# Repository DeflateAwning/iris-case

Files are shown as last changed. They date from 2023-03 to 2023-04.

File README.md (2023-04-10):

Iris Keyboard Case
==================

This repo contains the [Iris keyboard case](https://keeb.io/products/iris-keyboard-split-ergonomic-keyboard) design files. The case is a sandwich-style case with cutouts to accommodate the USB jack and the inter-half jack.

DeflateAwning Variation
-----------------------

The DeflateAwning variation removes the bottom FR/acrylic layer, decreasing the thickness of the whole board by 1.6mm, and simplifying the part count.

This version is for the Iris Rev 6, and has been tested on the Iris Rev. 6.1 PCB only. It may be compatible with other ones, but it might not be.

### Other changes:
* Uses M2x8mm thread-forming screws instead of bolts.
* Adds 3d-printable rubber feet.
* Adds "fuzzy skin" section to edges to make it easier to grip the edges of the keyboard and pull it into place.
* Smaller reset hole.

### Coming soon:
* Tenting stand.
* Better rotary encoder knobs.

**The rest of this README is copied from the upstream fork, and may not be accurate anymore.**

Please star my fork if you like this design, and especially if you end up printing/testing it. Feel free to open an Issue to request a feature.

Case pieces
-----------

The Iris sandwich case consists these pieces:

- Switch plate (Required)
- Bottom plate (Required)
- Middle layer (Optional)
- Top rim or Top shell (Optional)

### Case/Plate Versions

Before the release of the Iris Rev. 5 PCBs, the case parts for Rev. 3 & 4 used the same parts. However, with the release of Rev. 5-7 PCBs, the screw holes needed to be relocated to accommodate the wider USB-C port used for interconnect. Therefore, new case parts needed to be made to support the newer PCBs.

The newer case parts are called [Phoenix Edition (PE)](phoenix-edition-PE/), while the older Iris parts are now called [Legacy Edition (LE)](legacy-edition-LE).

Phoenix Edition parts and Legacy Edition parts are not compatible with each other due to the different placement of screw holes.

PE parts are compatible with Rev. 3 through 7 PCBs.

LE parts are compatible with Rev. 3 & 4 PCBs.

See additional info about Legacy Edition files in its [README](legacy-edition-LE/README.md).

Iris PE (Phoenix Edition) Parts
-------------------------------
### 3D-print STL files

For the 3D-print STL files, there are two sets of files, ones for the top shell, and ones for the middle layer. For each of these sets, there are different files based on how thick your plates are. If you have the FR4 plates or Stainless steel plates, then use the files for 1.5mm plate. If you are using 3mm acrylic plates, then use the files for the 3mm plate.

For the middle layer files for 1.5mm plates, there are two sets of files: one with a lip and one without a lip. The "lip" refers to the portion of the middle layer that extends past the standoffs and covers the sides of the 1.5mm plate, to hide the edges from view. The "No Lip" version may be more desirable for you to use if you are not using a top shell.

If you are using the top shells, you will need to use longer M2 screws, as the top shell has been designed to be threaded into directly from underneath. For 1.5mm plates, you will need [18mm screws](https://keeb.io/products/m2-screws-and-standoffs), and for 3mm plates, you will need 22mm screws.

If you choose to print the ErgoDox-style tenting legs, you will need six M3 screws (at least 16mm) and six M3 nuts. The legs and washers are best printed at 0.16mm quality or better.

Additional notes
----------------

Some of the files only have a left half, just mirror the file to produce a right half if needed.

Design info
-----------

A lot of these files have been derived from the following file: [iris-plate-design.ai](references/iris-plate-design.ai). By toggling various layers in that file, you can see various info on switch cutouts, screw holes, inner/outer edges, etc.

Screws and Standoffs
--------------------

This case was designed to use M2 screws and standoffs. The holes in the middle layers are for the standoffs, while the holes in the top and bottom layers are only wide enough for the screws. M2 screws and standoffs that fit the case can be purchased at Keebio: [M2 Screws & Standoffs](https://keeb.io/products/m2-screws-and-standoffs)

Fabrication of Acrylic Parts
----------------------------

### Places to go

- [Sculpteo](https://www.sculpteo.com)
- [Ponoko](https://www.ponoko.com)

### Middle Layer Thickness
If you're having the middle layers made, from the top of the switch plate to the top of the bottom plate, the minimum distance between the two required is 12mm if the plastic on the header pins is removed. The requirement is slightly more (about 13.5mm) if you leave the plastic on. Therefore, the following middle layer thickness are needed based on the thickness of the switch layer:

- 1.5mm Stainless steel switch plate: 10.5mm
    - Usually accomplished with:
        - 2x4.5mm + 1x1.5mm layers
        - or 3x3mm + 1x1.5mm layers
        - or 4x3mm layers
- 3mm acrylic switch plate: 9mm
    - Usually accomplished with:
        - 2x4.5mm layers
        - or 3x3mm layers

STL Files for 3D printing
-------------------------
A couple of STL files have also been included for the middle layers and are both single pieces. They are designed for the left half, so to get the right half, you will need to flip them within your slicer software.

One version allows the Ergodox EZ legs to be used with it. In addition to the legs, you'll need M3 nuts to allow the legs screws to screw into.

Community-Made Files
--------------------
Files not designed by Keebio are placed into the [community-made](community-made/) folder and also includes links to other designs not hosted in this repository.

License
-------
These case files are released under the MIT License.

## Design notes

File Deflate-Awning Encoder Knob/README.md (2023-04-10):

# Deflate-Awning Encoder Knob

An encoder knob for the standard encoder on the Iris keyboard.

## Print Settings
* Enable Fuzzy Skin
* Make Fuzzy Skin deeper by 0.5mm

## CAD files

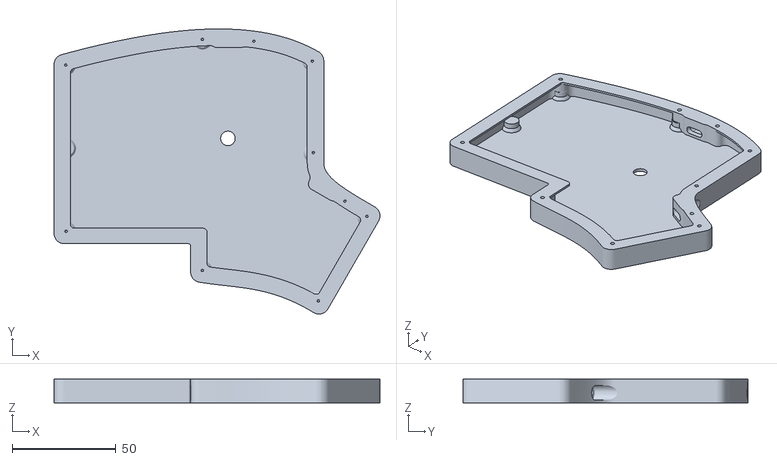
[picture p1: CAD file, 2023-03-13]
phoenix-edition-PE/DeflateAwning Version/Iris PE Redesign v1 - Main Case.stl
157.4 x 137.7 x 11.5

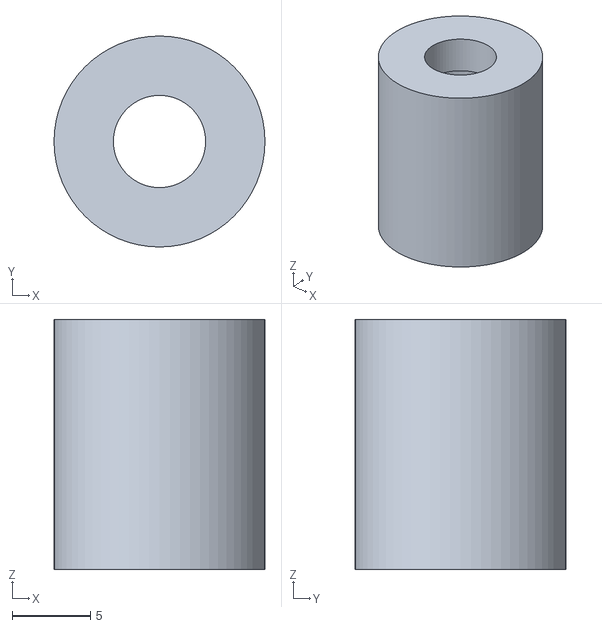
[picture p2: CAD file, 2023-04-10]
Deflate-Awning Encoder Knob/KeyboardEncoderKnob.stl
13.5 x 13.5 x 16.0

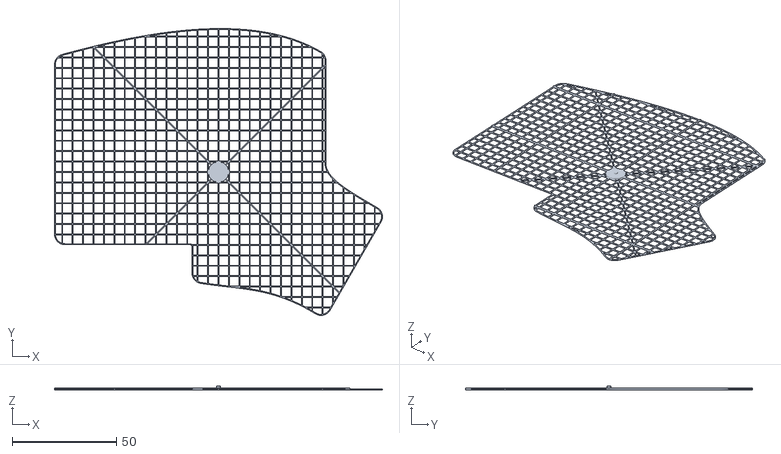
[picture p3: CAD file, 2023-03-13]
phoenix-edition-PE/DeflateAwning Version/Iris PE Redesign v1 - 5mm Test Grid.stl
157.4 x 137.7 x 1.80

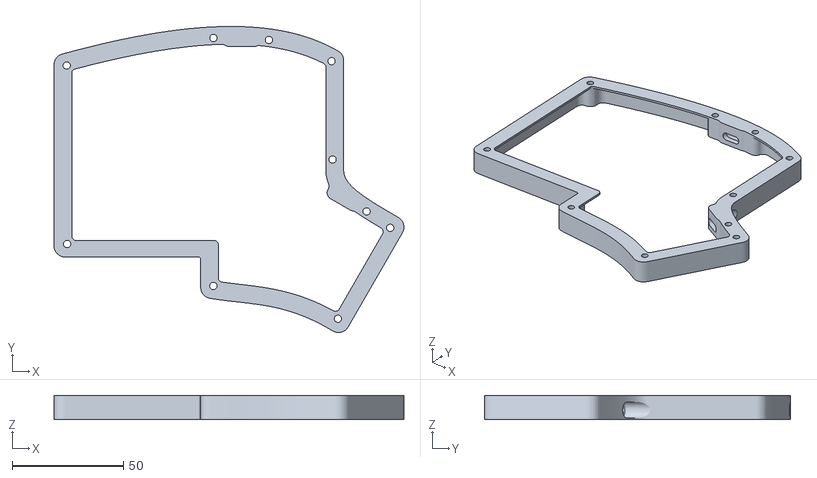
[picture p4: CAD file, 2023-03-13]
phoenix-edition-PE/Iris PE Middle Layer - Normal No Lip for 1.5mm Plate - Centered.stl
157.4 x 137.7 x 11.0

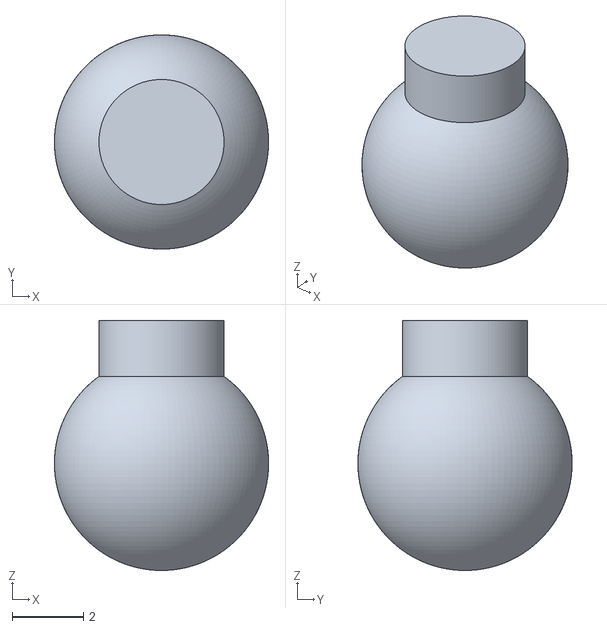
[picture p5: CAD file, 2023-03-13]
phoenix-edition-PE/DeflateAwning Version/Iris PE Redesign v1 - Balls.stl
6.00 x 6.00 x 7.00

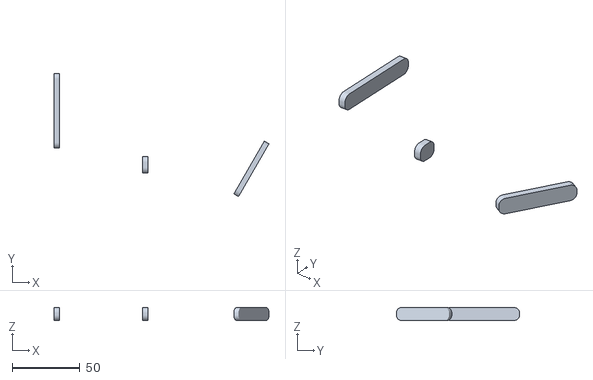
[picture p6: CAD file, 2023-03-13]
phoenix-edition-PE/DeflateAwning Version/Iris PE Redesign v1 - fuzzy_region_modifier.stl
158.7 x 91.0 x 9.50

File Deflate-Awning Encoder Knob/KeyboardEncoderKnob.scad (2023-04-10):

shaftD = 5.9;

outD = 13.5;

h = 16;

clearD = 10;
clearH = 13;

$fn = 64;

MakeIt();

module MakeIt() {
    difference() {
        
        cylinder(d=outD, h=h);
        
        cylinder(d=shaftD, h=h);
        
        cylinder(d=clearD, h=clearH);
        
    }
}

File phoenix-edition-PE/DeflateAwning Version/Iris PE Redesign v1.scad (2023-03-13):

include <BOSL2/std.scad>;

// Fuzzy Skin Settings:
// Distance: 0.7mm
// Thickness: 1.0mm

//filename = "../Iris PE Middle Layer - Normal No Lip for 1.5mm Plate.stl";
filename = "../Iris PE Middle Layer - Normal No Lip for 1.5mm Plate - Centered.stl";
outline_filename = "openscad_gen - Iris PE Normal No Lip Outline.dxf";

import_size_x = 157.44;
import_size_y = 137.69;
import_size_z = 11;

tilt_angle_deg = 20;
tilt_angle_deg_vector = [0, -20, 0];

screw_depth = 8-1; // screw len minus FR4 plate thickness
screw_d = 1;

ball_d = 6;
ball_cyl_d = 3.5;
ball_cyl_h = 1;

holes_xy = [[-7, -47.9], [-72.8, -29], [-73, 51.3], [-7, 63.7], [17.9, 62.8], [46.1, 53.2], [46.6, 9], [61.9, -14.4], [72.5, -21.8], [49, -62.6]];
ball_loc_xy = [[-7, -47.9], [-72.8, -29], [-72.9, (51.3-29)/2], [-73, 51.3], [-7, 63.7], [46.1, 53.2], [46.6, 9], [72.5, -21.8], [49, -62.6]];

// bot_left_ball_xy = [-72.8, -29]; // for indexing the reset switch position

bot_t_total = 1.5;
bot_overlap = 1;
bot_t_nonoverlap = bot_t_total - bot_overlap;

total_h = import_size_z + bot_t_nonoverlap;


echo("Amount of screw that goes into the ball part below: ", -(total_h-screw_depth-ball_d/2-ball_cyl_h), " (negative means not intersecting)");

$fn = 100;


//import_outline();

//create_plate();
make_main_case();
//make_balls();

//make_sizing_grid();
//fuzzy_region_modifier();

module import_model() {
	import(filename);
}

module import_outline() {
	import(outline_filename);
}

module create_solid_import() {
	// creates a "solid" version (in 2D) of the outline
	// saved, because it takes forever to render
	for (i = [0.01:0.001:1]) {
		scale([i, i, 1]) projection(false) import_file();
	}

	circle(d=50);
}

module make_main_case () {
	difference() {
		union() {
			up(bot_t_nonoverlap) {
				import_model();
				for (xy = holes_xy) translate([xy[0], xy[1], 0]) zcyl(d=5, h=import_size_z, anchor=BOTTOM);
			}

			linear_extrude(height = bot_t_total) import_outline();

			
			// add supports around balls
			for (xy = ball_loc_xy) translate([xy[0], xy[1], 0]) {
				zcyl(d=ball_cyl_d+4, h=ball_d/2+ball_cyl_h+2, anchor=BOTTOM);
				intersection() {
					spheroid(d=ball_d+4, anchor=CENTER, $fn=50);
					cuboid([1000, 1000, 1000], anchor=BOTTOM);
				}
			}
		}

		// remove screw holes to top board
		for (xy = holes_xy) translate([xy[0], xy[1], 0]) {
			up(total_h) zcyl(d=screw_d, h=screw_depth, anchor=TOP);
			up(total_h) zcyl(d1=screw_d, d2=2, h=0.8, anchor=TOP); // add registration hole for easy screwing
		}

		// remove reset/programming hole
		//translate([-import_size_x/2 + 83.7, import_size_y/2 - 52.5, 0]) zcyl(d=12, h=100);
		echo("Programming hole location (original): ", -import_size_x/2 + 83.7, import_size_y/2 - 52.5); //  4.98, 16.345
		//% translate([-import_size_x/2 + 83.7, import_size_y/2 - 52.5, 0]) cuboid([8, 8, 30], rounding=2.5, except=[TOP, BOTTOM]);
		translate([5.27, 15.98, 0]) zcyl(d=7, h=50); //cuboid([8, 8, 30], rounding=2.5, except=[TOP, BOTTOM]);
	
		// remove places for balls
		for (xy = ball_loc_xy) translate([xy[0], xy[1], 0]) {
			zcyl(d=ball_cyl_d, h=ball_d/2+ball_cyl_h, anchor=BOTTOM);
			spheroid(d=ball_d, anchor=CENTER);
		}

	}

}

module create_plate() {
	rot(tilt_angle_deg_vector, cp=[-import_size_x/2, 0, 0])

	//linear_extrude(height = 5) import_outline(); 

	//extrude_from_to([import_size_x/2, import_size_y/2, 0], [import_size_x/2, import_size_y/2, 20], twist=10) import_outline();
	
	difference() {
		translate([-import_size_x/2, -import_size_y/2, 0]) xflip() zrot(180) xrot(90)
			rotate_extrude(angle=tilt_angle_deg, $fn=1000)
			translate([import_size_x/2+0.001, import_size_y/2+0.001, 0]) import_outline();

		translate([-import_size_x/2, -import_size_y/2, 0]) yrot(1) xflip() zrot(180) xrot(90)
			rotate_extrude(angle=tilt_angle_deg+3, $fn=1000)
			translate([import_size_x/2+0.001, import_size_y/2+0.001, 0]) offset(r=-10) import_outline();

	}

}

//import("iris-PE-bottom-plate_outline.dxf.svg", center=true);

module make_sizing_grid() {
	/*difference() {
		linear_extrude(height = 0.4) import_outline();

		grid_copies(spacing = 5, size = 250) zcyl(d=4, h=100, $fn=24);
	}*/

	grid_test_h = 0.4;

	linear_extrude(height = grid_test_h) difference() {
		import_outline();
		offset(-0.45) import_outline();
	}

	intersection() {
		union() {
			xcopies(spacing = 5, n = 51) cuboid([0.45, 1000, grid_test_h], anchor=BOTTOM);
			ycopies(spacing = 5, n = 51) cuboid([1000, 0.45, grid_test_h], anchor=BOTTOM);
			
			xcopies(spacing = 50, n = 11) cuboid([0.45, 1000, grid_test_h*2], anchor=BOTTOM);
			ycopies(spacing = 50, n = 11) cuboid([1000, 0.45, grid_test_h*2], anchor=BOTTOM);

			zrot(45) cuboid([0.45, 1000, grid_test_h], anchor=BOTTOM);
			zrot(-45) cuboid([0.45, 1000, grid_test_h], anchor=BOTTOM);
		}
		linear_extrude(height = 100) import_outline();
	}

	zcyl(d=10, h=1, $fn=12, anchor=BOTTOM);
	zcyl(d=2, h=1.8, anchor=BOTTOM);

}

module fuzzy_region_modifier() {
	fuzzy_rounding = 4;

	// bottom-right
	translate([63.5, -45, 0]) up(1) zrot(-30) cuboid([4, 45, total_h-2], rounding=fuzzy_rounding, except=[RIGHT, LEFT], anchor=BOTTOM+LEFT);

	// center bottom region
	translate([-15, -43, 0]) up(1) cuboid([4, 12, total_h-2], rounding=fuzzy_rounding, except=[RIGHT, LEFT], anchor=BOTTOM+LEFT);

	// left edge
	translate([-80.5, -3, 0]) up(1) cuboid([4, 55, total_h-2], rounding=fuzzy_rounding, except=[RIGHT, LEFT], anchor=BOTTOM+LEFT);
}

module make_balls() {
	zcyl(d=ball_cyl_d - 0.5, h=ball_d/2+ball_cyl_h - 0.6, anchor=BOTTOM);
	spheroid(d=ball_d, anchor=CENTER);

}

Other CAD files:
phoenix-edition-PE/DeflateAwning Version/openscad_gen - Iris PE Normal No Lip Outline.dxf

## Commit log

2023-03-13 Add my first upgrade files
    [Iris PE Middle Layer - Normal No Lip for 1.5mm Plate - Centered.stl, Iris PE Redesign v1 - 5mm Test Grid.stl, Iris PE Redesign v1 - Balls.stl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]
2023-03-13 Re-arrange files
    [Iris PE Redesign v1 - 5mm Test Grid.stl, Iris PE Redesign v1 - Balls.stl, Iris PE Redesign v1 - Main Case.stl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]
2023-03-13 Fix paths
    [Iris PE Redesign v1.scad]
2023-04-10 Add v1 encoder knob
    [KeyboardEncoderKnob.scad, KeyboardEncoderKnob.stl]
2023-04-10 Add v2 encoder knob
    [KeyboardEncoderKnob.scad, KeyboardEncoderKnob.stl]
